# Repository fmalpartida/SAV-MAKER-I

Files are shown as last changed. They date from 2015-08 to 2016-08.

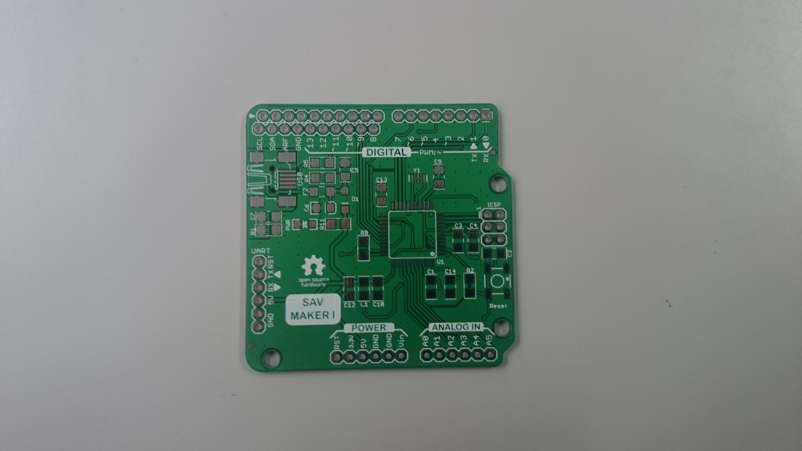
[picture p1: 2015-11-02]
assembly guide/Images/PCBWithoutComponents.JPG

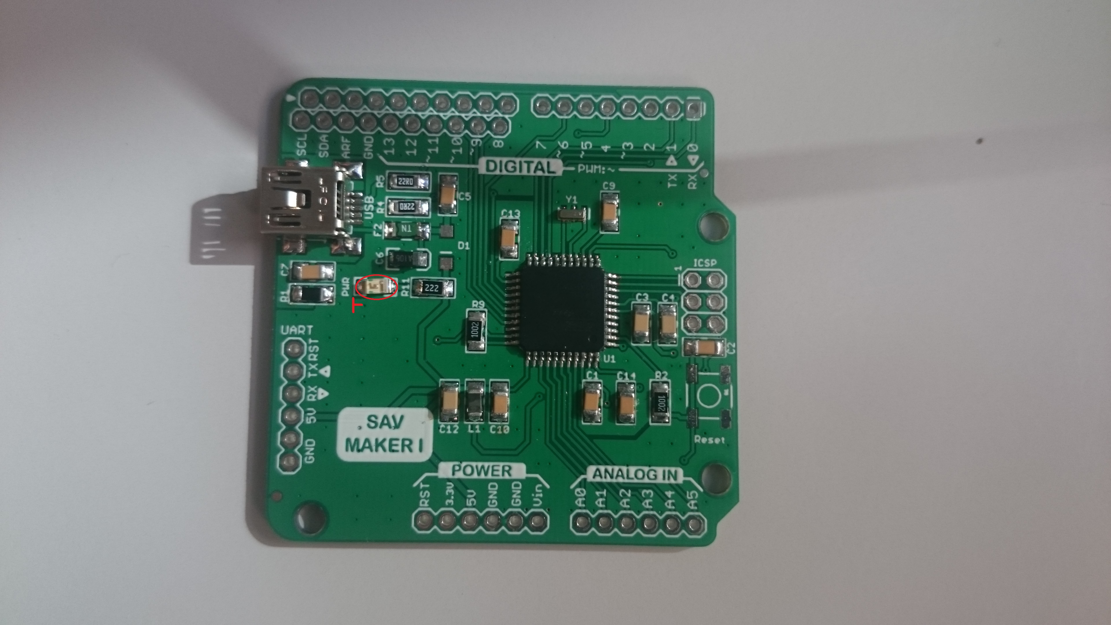
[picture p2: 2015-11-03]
assembly guide/Images/PlacingLed.JPG

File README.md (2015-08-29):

# SAV-MAKER-I
## Introduction

The SAV MAKER I is an “open hardware” project made in Spain and based on the popular [vinciDuino board](https://bitbucket.org/fmalpartida/vinciduino/wiki/Home), 
predecessor of Arduino's Leonardo board and fully compatible with it. 
This development has been carried out for the Telecom Engineering "Applied Electronics" course carried out in the
UMA (Universidad de Málaga). On day one, students will receive a bare PCB and a set of components to assemble and 
use it on some of their course projects.

![SAV MAKER I Rev A] (https://github.com/fmalpartida/SAV-MAKER-I/blob/master/images/SAV%20MAKER%20I%20Rev%20A%20-%20PCBs.JPG)

The SAV MAKER I is an “open hardware” project, a board with an 8-bit microcontroller similar to the Arduino Leonardo
and fully compatible with it. The spirit behind it is for students to be able to build and user their own tools, 
analyse, build on and share their work.
At the end of the year, the board will be revised with their contributions, and who knows, we may use the highest rated board
on next year's course. It will be fun to see how the board evolves over the years.

Beign an open project where anyone can be part of the design team; anyone can bring knowledge, comments and ideas for 
developing other Arduino compatible training board or a programmable board using the Atmel environment without an 
external programmer. It is not limited to students. However, in comparison with other similar “open hardware” projects the 
SAV MAKER I has been designed for people to learn, build and use it while being cost effective. The cost has been optimized
as much as possible to accomodate any budget and pursue the real open hardware’s spirit.

## Wiki contents
* [SAV MAKER I wiki home](https://github.com/fmalpartida/SAV-MAKER-I/wiki)
* [Specifications](https://github.com/fmalpartida/SAV-MAKER-I/wiki/Specifications)
* [Board assembly and mechanical drawings](https://github.com/fmalpartida/SAV-MAKER-I/wiki/Mechanical-drawings-and-component-placement)
* [Board assembly step by step](https://github.com/fmalpartida/SAV-MAKER-I/wiki/Assembly-guide)

## Licensing
All information contained herein is licensed under [CERN OHL](http://www.ohwr.org/attachments/2388/cern_ohl_v_1_2.txt) (please refer to license file for details), so if someone 
wants to use this information to assemble kits, sell boards, etc. … feel free to do it.

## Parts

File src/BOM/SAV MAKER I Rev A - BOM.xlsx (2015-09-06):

Qty | Value | Parts | Device | Mouser part | Price | TOTAL
3 |  | JP3, JP5, JP6 | M06SIP |  |  | 0
1 |  | JP4 | M081X08 |  |  | 0
1 |  | S1 | TAC_SWITCHSMD | PTS525S | 0.23 | 0.23
7 | 0.1uF | C1, C2, C5, C9, C10, C13, C14 | CAP1206 | VJ1206Y104KXXCW1BC | 0.028 | 0.196
2 | 10K | R2, R9 | R-US_R1206 | CRCW120610K0FKEA | 0.029 | 0.058
1 | 10uF | C6 | CAP_POL1206 | F931A106MAA | 0.1 | 0.1
1 | 1206L | F2 | PTC1206_L | 504-PTS120616V025 | 0.29 | 0.29
1 | 1M | R1 | R-US_R1206 | RC1206FR-071ML | 0.009 | 0.009
3 | 1uF | C3, C4, C12 | CAP1206 | VJ1206Y105MXJTW1BC | 0.033 | 0.099
2 | 22R | R4, R5 | R-US_R1206 | ERJ-8ENF22R0V | 0.019 | 0.038
1 | 2K2 | R11 | R-US_R1206 | CRCW12062K20JNEA | 0.012 | 0.012
1 | 4.7nF | C7 | CAP1206 | VJ1206Y472KXXCW1BC | 0.03 | 0.03
1 | ATMEGA32U4-AU | U1 | ATMEGA32U4-AU | ATMEGA32U4-AU | 4.91 | 4.91
1 | AVR_SPI_PRG_6PTH | J2 | AVR_SPI_PRG_6PTH |  |  | 0
1 | MINI USB | USB | MINI-USB-SCHIELD-32005-201 | 10033526-N3212LF | 0.54 | 0.54
1 | Ferrite | L1 | WE-CBF_1206W | 2512061027Y1 | 0.057 | 0.057
2 | M10";M10"" | Header 10 | 1X10 |  |  | 0
1 | MBR0520LT | D1 | MBR0520LT | MBR0520LT1G | 0.2 | 0.2
1 | RESONATORSMD | Y1 | RESONATORSMD | CSTCE16M0V53-R0 | 0.274 | 0.274
1 | Red | PWR | LED1206 | SML-LXF1206GC-TR | 0.09 | 0.09
1 | SAV Maker I | A | BOARD_INFO_BMP_20 |  | 4.5 | 4.5
 |  |  |  |  | TOTAL | 11.633

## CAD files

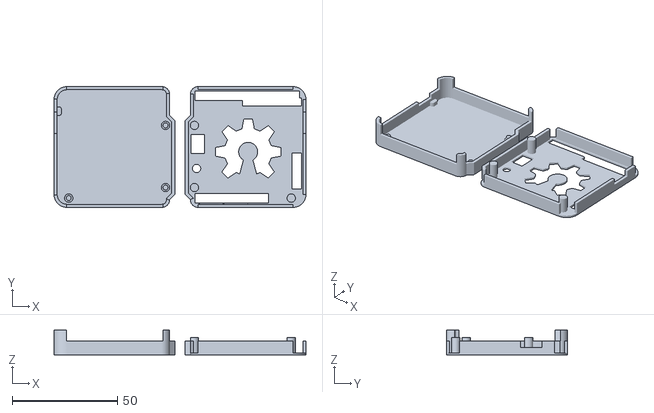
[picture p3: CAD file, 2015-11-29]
3D models/STL Files/SAV_M_I_CASE_v1.4.stl
119.6 x 57.4 x 11.8

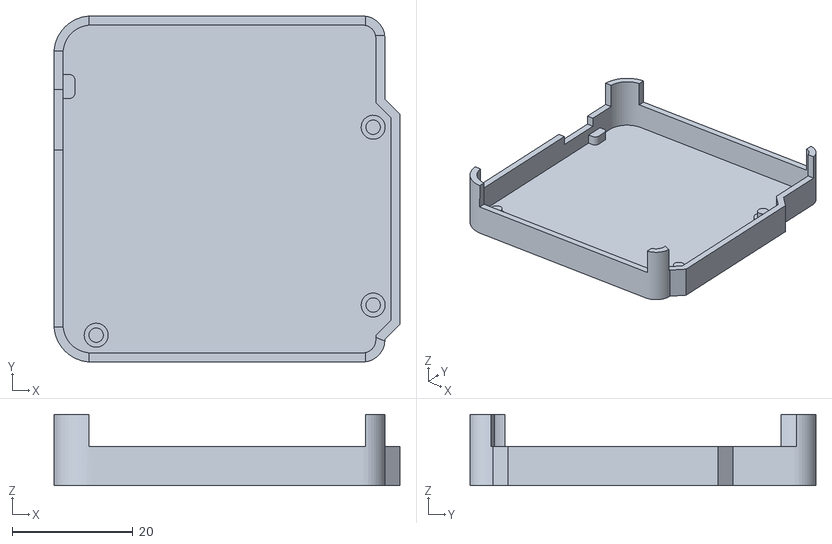
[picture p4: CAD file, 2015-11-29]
3D models/STL Files/SAV_M_I_CASE_v1.3_bottom.stl
57.4 x 57.4 x 11.8

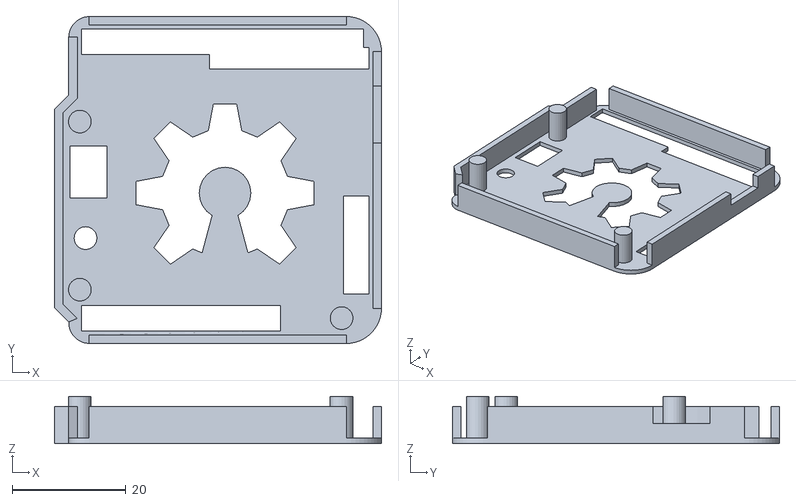
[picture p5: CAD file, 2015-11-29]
3D models/STL Files/SAV_M_I_CASE_v1.4_top.stl
57.4 x 57.4 x 8.30

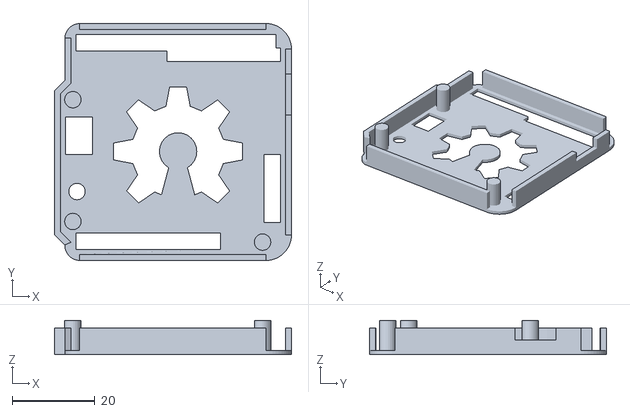
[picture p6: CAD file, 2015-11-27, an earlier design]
3D models/STL Files/SAV_M_I_CASE_v1.3_top.stl
57.4 x 57.4 x 8.30

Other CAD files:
3D models/STL Files/SAV_M_I_CASE_v1.3.stl
3D models/STL Files/SAV_M_I_CASE_v1.2_bottom.stl
3D models/Sketchup Files/SAV_M_I_CASE_v1.2.skp
3D models/Sketchup Files/SAV_M_I_CASE_v1.3.skp
3D models/Sketchup Files/SAV_M_I_CASE_v1.4.skp

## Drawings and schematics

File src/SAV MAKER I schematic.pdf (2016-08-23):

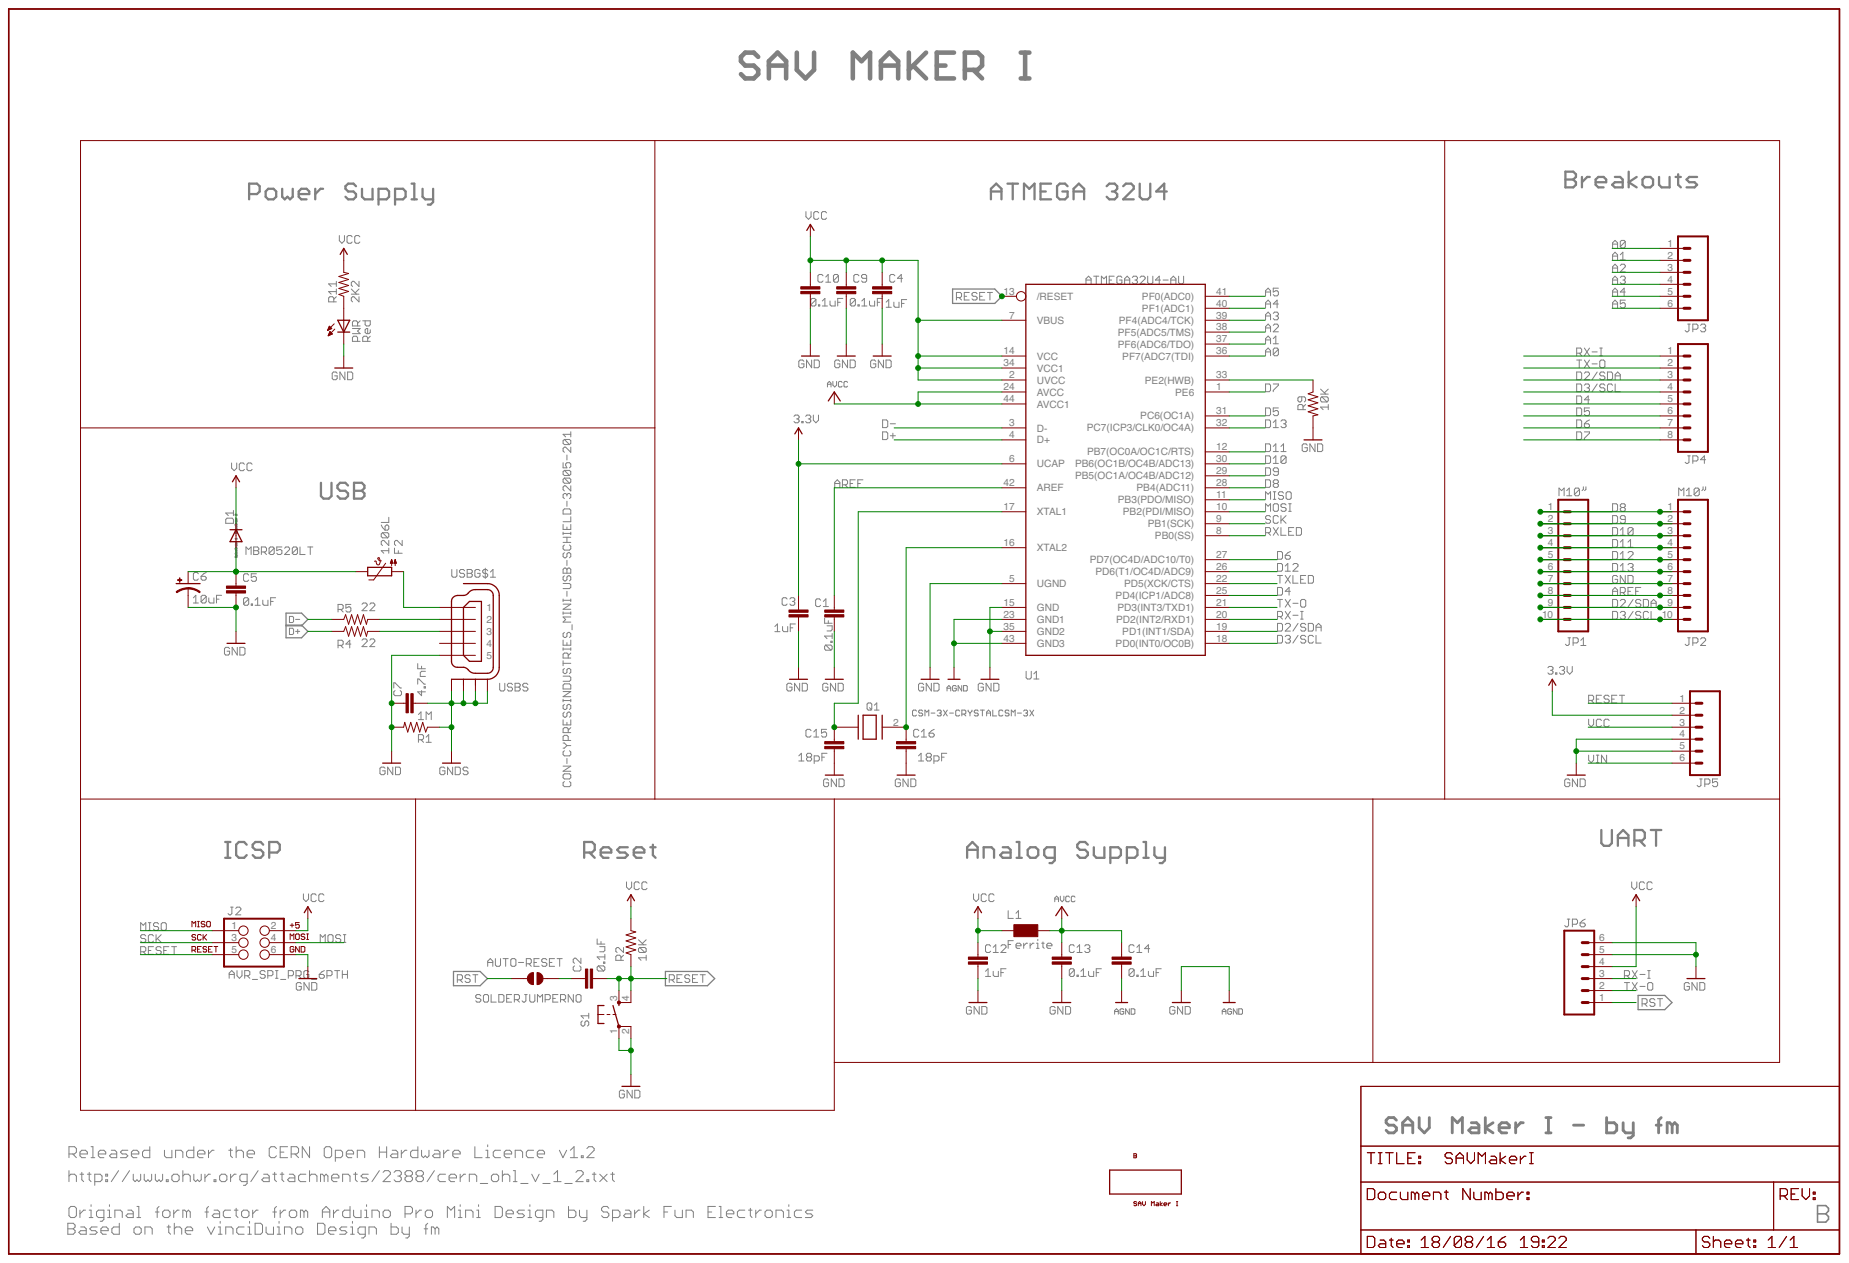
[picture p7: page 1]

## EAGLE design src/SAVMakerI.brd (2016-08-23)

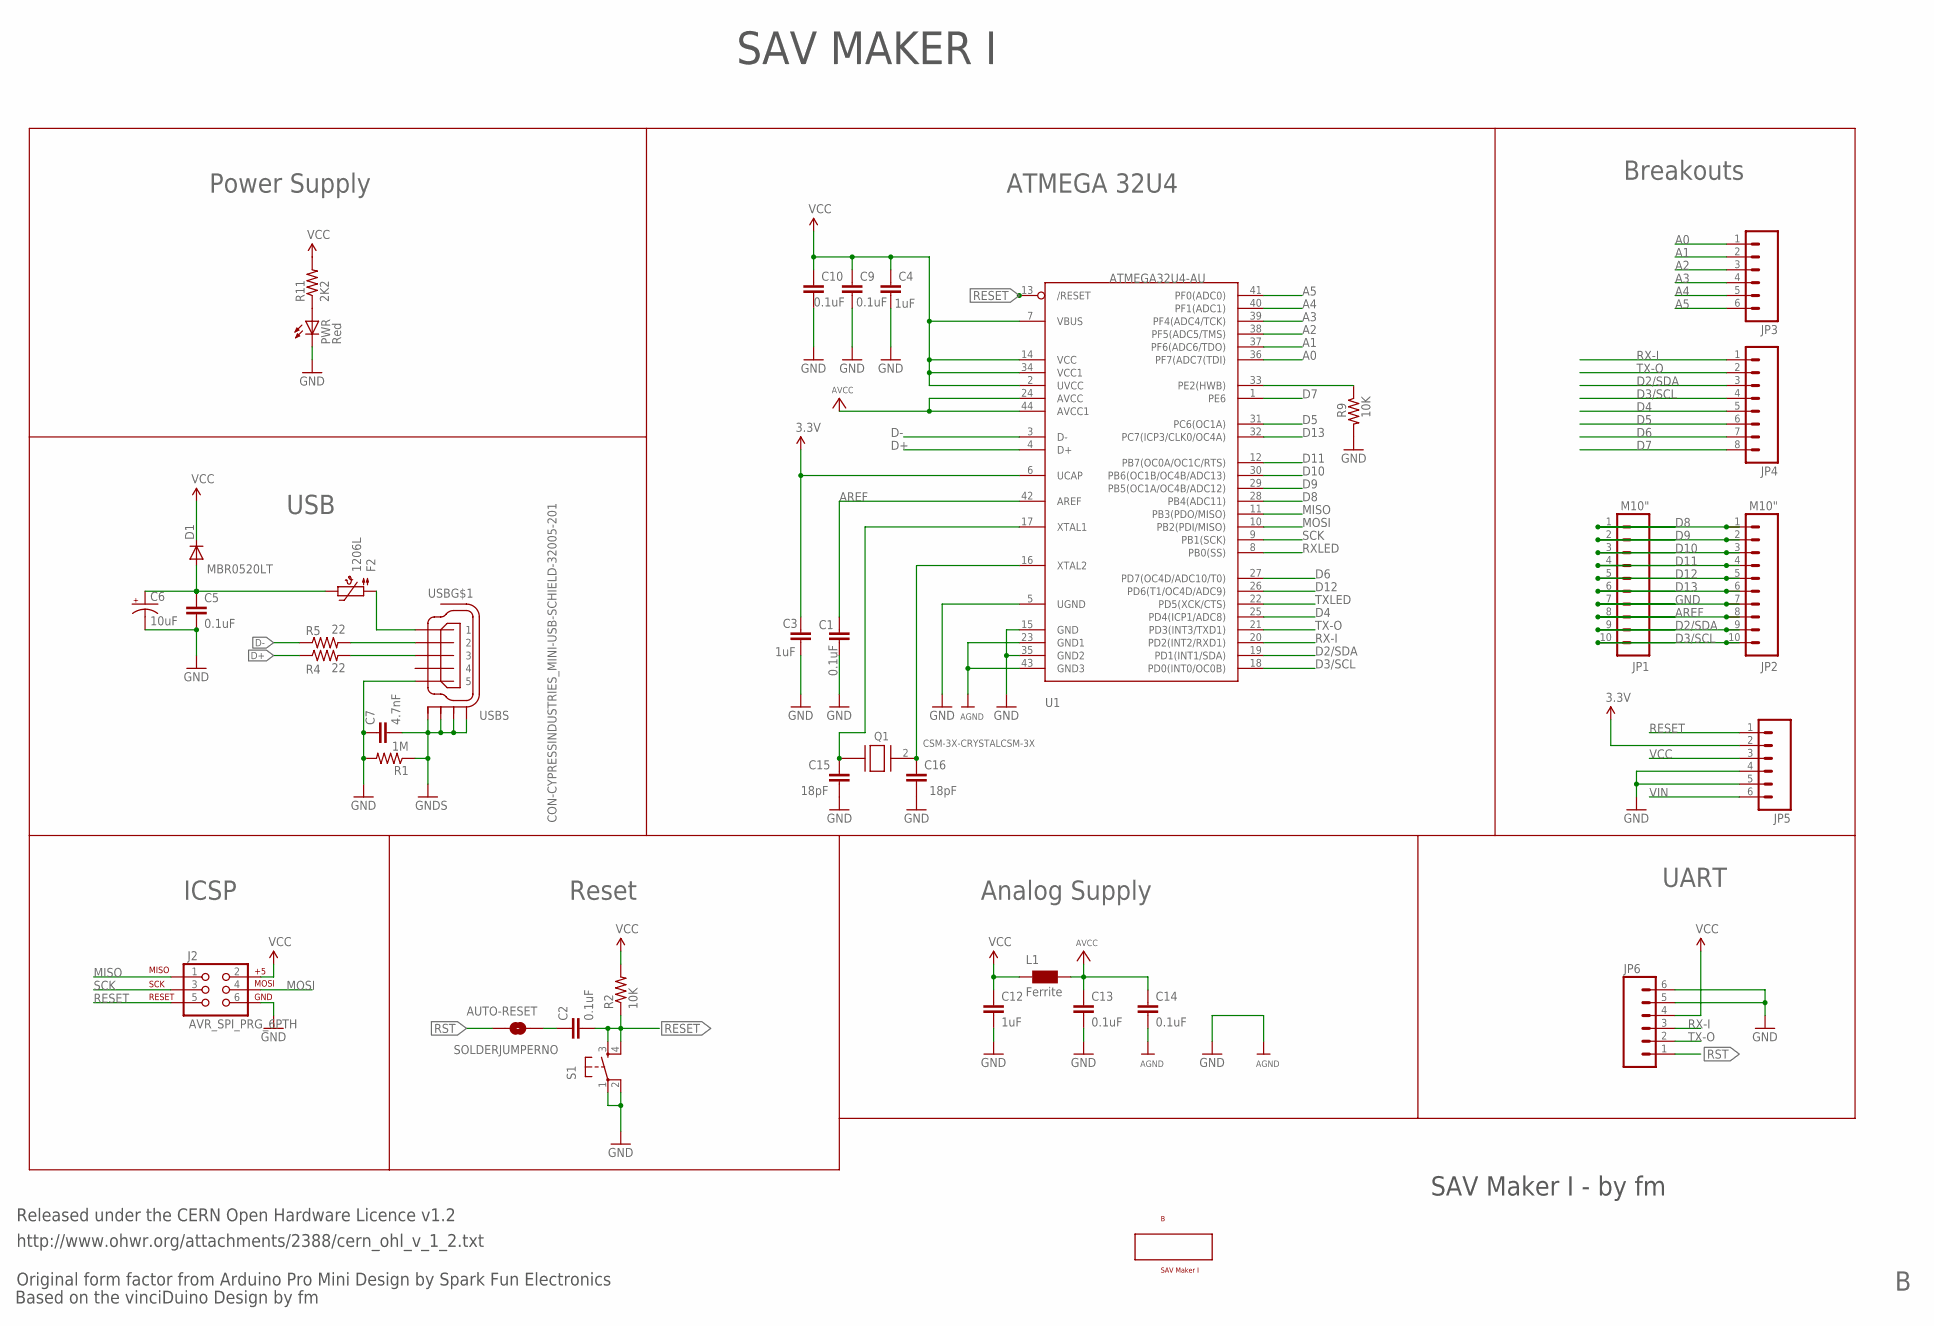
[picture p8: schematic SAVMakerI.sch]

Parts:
AUTO-RESET: SOLDERJUMPERNO; SJ_2S-NO
B: SAV Maker I; BOARD_INFO_BMP
C1, C2, C5, C9, C10, C13, C14: 0.1uF; 1206
C3, C4, C12: 1uF; 1206
C6: 10uF; EIA3216
C7: 4.7nF; 1206
C15, C16: 18pF; 1206
D1: MBR0520LT; SOD123
F2: 1206L; 1206_PTC
J2: AVR_SPI_PRG_6PTH; 2X3
JP1, JP2: M10"; 1X10
JP3, JP5, JP6: M06SIP; 1X06
JP4: M081X08; 1X08
L1: Ferrite; 1206W
PWR: Red; LED-1206
Q1: CSM-3X-CRYSTALCSM-3X; CSM-3X
R1: 1M; R1206
R2, R9: 10K; R1206
R4, R5: 22; R1206
R11: 2K2; R1206
S1: TAC_SWITCHSMD; TACTILE_SWITCH_SMD
U1: ATMEGA32U4-AU; ADAFRUIT_TQFP44
USB: CON-CYPRESSINDUSTRIES_MINI-USB-SCHIELD-32005-201; CON-CYPRESSINDUSTRIES_32005-201

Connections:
3.3V: C3.1, JP5.2, U1.6 (UCAP)
A0: JP3.1, U1.36 (PF7(ADC7(TDI))
A1: JP3.2, U1.37 (PF6(ADC6/TDO))
A2: JP3.3, U1.38 (PF5(ADC5/TMS))
A3: JP3.4, U1.39 (PF4(ADC4/TCK))
A4: JP3.5, U1.40 (PF1(ADC1))
A5: JP3.6, U1.41 (PF0(ADC0))
AREF: C1.2, JP1.8, JP2.8, U1.42 (AREF)
AVCC: C13.1, C14.1, L1.2, U1.24 (AVCC), U1.44 (AVCC1)
D2/SDA: JP1.9, JP2.9, JP4.3, U1.19 (PD1(INT1/SDA))
D3/SCL: JP1.10, JP2.10, JP4.4, U1.18 (PD0(INT0/OC0B))
D4: JP4.5, U1.25 (PD4(ICP1/ADC8))
D5: JP4.6, U1.31 (PC6(OC1A))
D6: JP4.7, U1.27 (PD7(OC4D/ADC10/T0))
D7: JP4.8, U1.1 (PE6)
D8: JP1.1, JP2.1, U1.28 (PB4(ADC11))
D9: JP1.2, JP2.2, U1.29 (PB5(OC1A/OC4B/ADC12))
D10: JP1.3, JP2.3, U1.30 (PB6(OC1B/OC4B/ADC13))
D11: JP1.4, JP2.4, U1.12 (PB7(OC0A/OC1C/RTS))
D12: JP1.5, JP2.5, U1.26 (PD6(T1/OC4D/ADC9))
D13: JP1.6, JP2.6, U1.32 (PC7(ICP3/CLK0/OC4A))
D+: R4.1, U1.4 (D+)
D-: R5.1, U1.3 (D-)
GND: C1.1, C3.2, C4.2, C5.2, C6.C (-), C7.1, C9.2, C10.2, C12.2, C13.2, C14.2, C15.2, C16.2, J2.6, JP1.7, JP2.7, JP5.4, JP5.5, JP6.5, JP6.6, PWR.C, R1.2, R9.2, S1.1, S1.2, U1.5 (UGND), U1.15 (GND), U1.23 (GND1), U1.35 (GND2), U1.43 (GND3), USB.5
GNDS: C7.2, R1.1, USB.M1 (S1), USB.M2 (S2), USB.M3 (S3), USB.M4 (S4)
MISO: J2.1, U1.11 (PB3(PDO/MISO))
MOSI: J2.4, U1.10 (PB2(PDI/MISO))
unnamed: R5.2, USB.2
unnamed: C16.1, Q1.2, U1.16 (XTAL2)
unnamed: C15.1, Q1.1, U1.17 (XTAL1)
unnamed: R4.2, USB.3
unnamed: R9.1, U1.33 (PE2(HWB))
unnamed: AUTO-RESET.2, C2.1
unnamed: F2.1, USB.1
unnamed: PWR.A, R11.1
RESET: C2.2, J2.5, JP5.1, R2.1, S1.3, S1.4, U1.13 (/RESET)
RST: AUTO-RESET.1, JP6.1
RX-I: JP4.1, JP6.3, U1.20 (PD2(INT2/RXD1))
RXLED: U1.8 (PB0(SS))
SCK: J2.3, U1.9 (PB1(SCK))
TX-O: JP4.2, JP6.2, U1.21 (PD3(INT3/TXD1))
TXLED: U1.22 (PD5(XCK/CTS))
VBUS: C5.1, C6.A (+), D1.A, F2.2
VCC: C4.1, C9.1, C10.1, C12.1, D1.C, J2.2, JP5.3, JP6.4, L1.1, R2.2, R11.2, U1.2 (UVCC), U1.7 (VBUS), U1.14 (VCC), U1.34 (VCC1)
VIN: JP5.6

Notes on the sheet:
Released under the CERN Open Hardware Licence v1.2
http://www.ohwr.org/attachments/2388/cern_ohl_v_1_2.txt
Original form factor from Arduino Pro Mini Design by Spark Fun Electronics
Based on the vinciDuino Design by fm
Power Supply
USB
Reset
ICSP
Analog Supply
UART
Breakouts
ATMEGA 32U4
SAV MAKER I
SAV Maker I - by fm

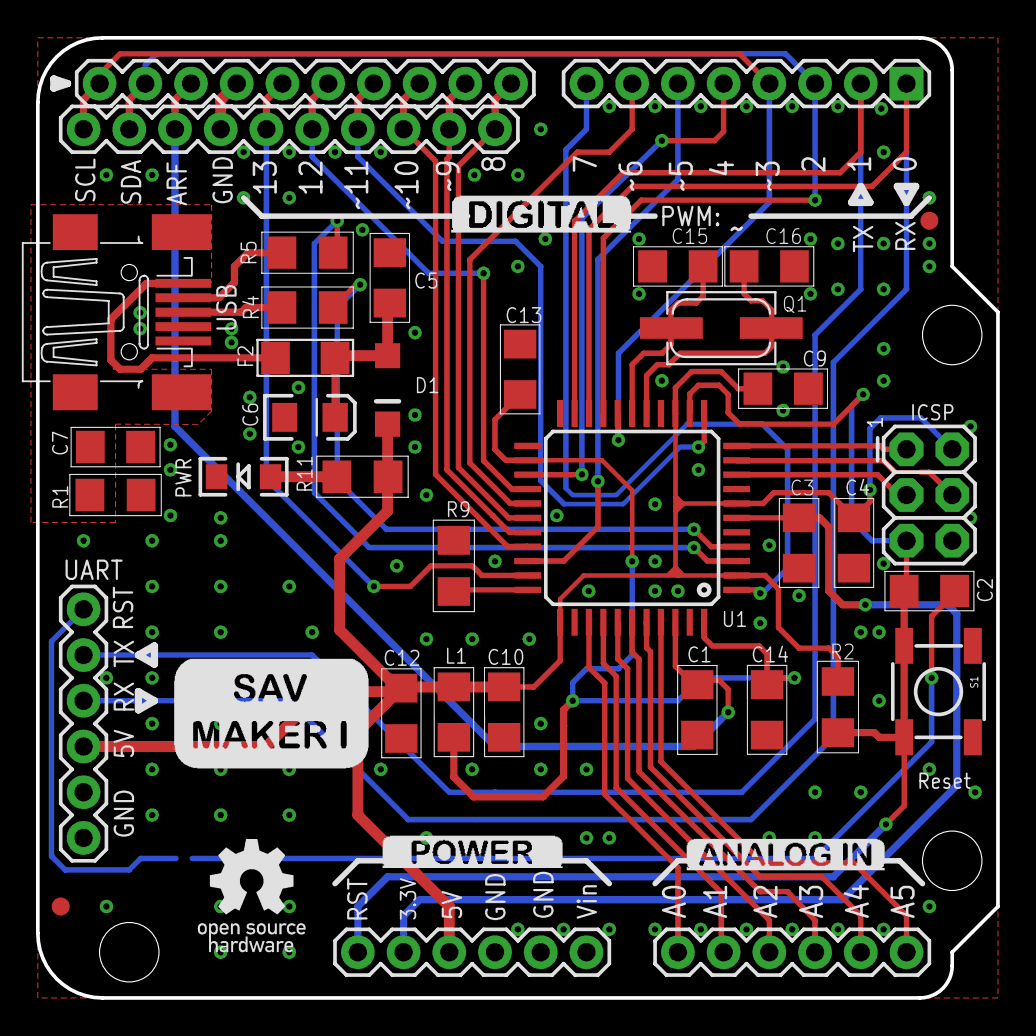
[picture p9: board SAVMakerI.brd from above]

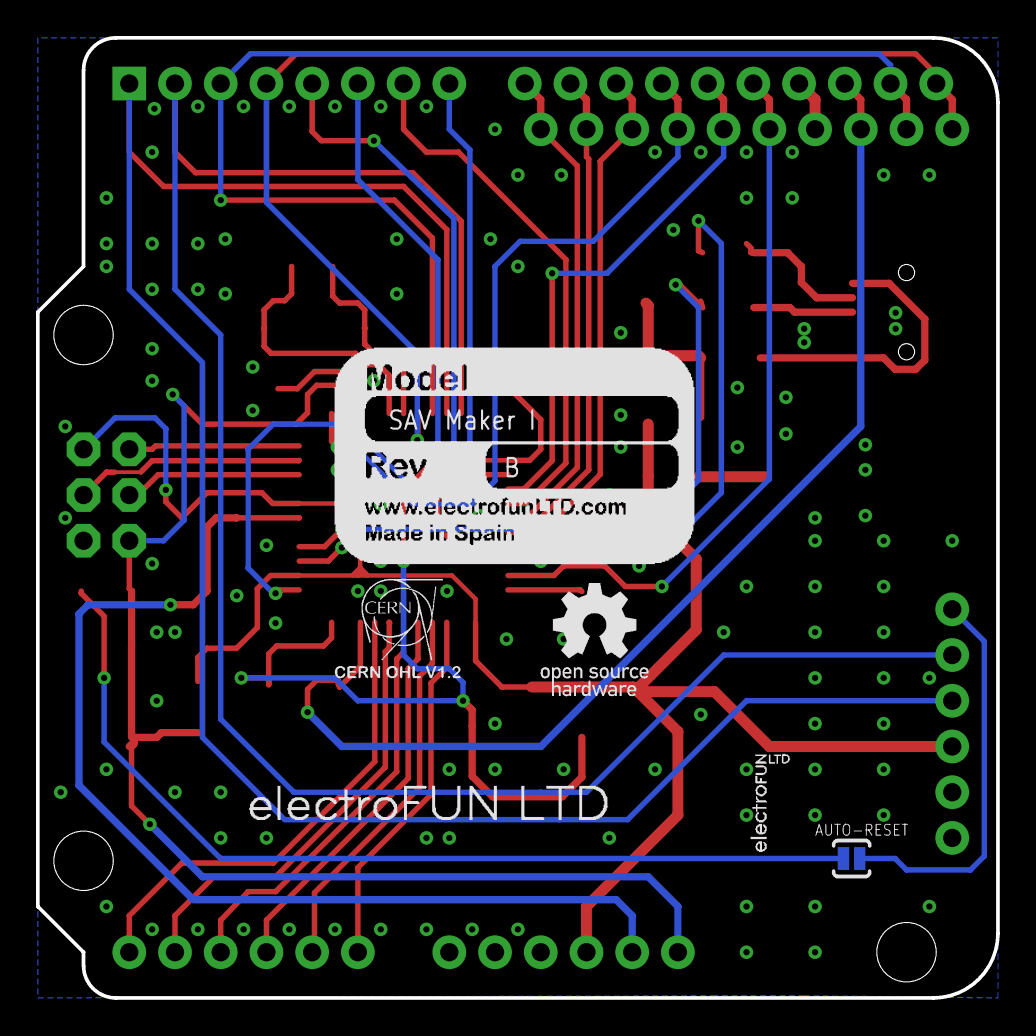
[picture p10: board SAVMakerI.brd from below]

Board: 2 copper layers, 53.3 x 53.3 mm, 50 parts (5 on the bottom side), 42 nets.

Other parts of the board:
U$1, U$3, U$5: STAND-OFF
U$2, U$4: FIDUCIAL1X2; FIDUCIAL-1X2
U$9: ELECTROFUN_STRIP
U$10: SAVMAKERI
U$13, U$15: OSHW
U$14: CERN_OHL
U$16: ANALOG_BMP
U$17: DIGITAL_BMP
U$18: POWER_BMP

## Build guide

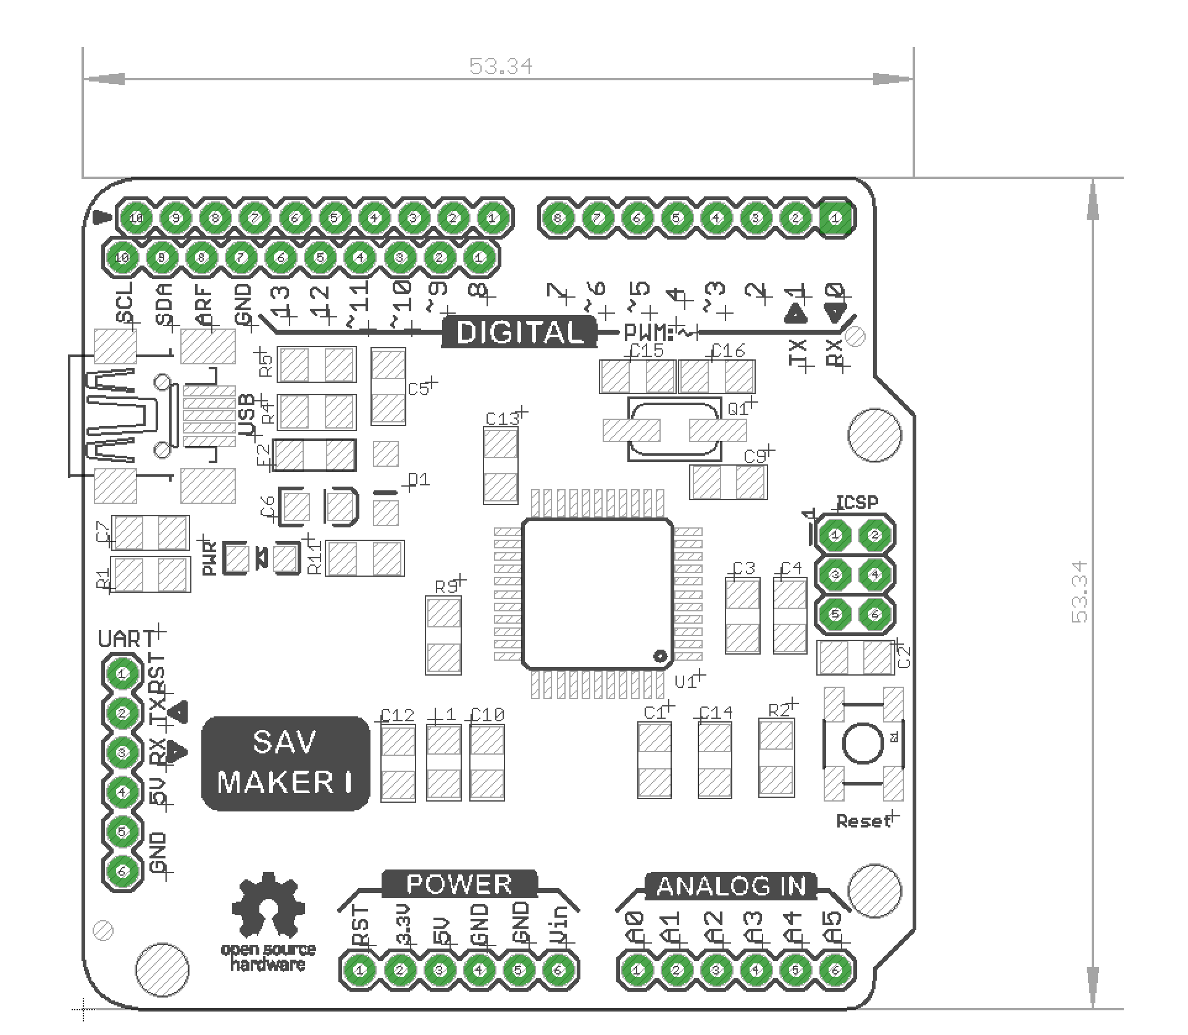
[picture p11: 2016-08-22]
images/RevB/SAV MAKER I RevB - assembly.png

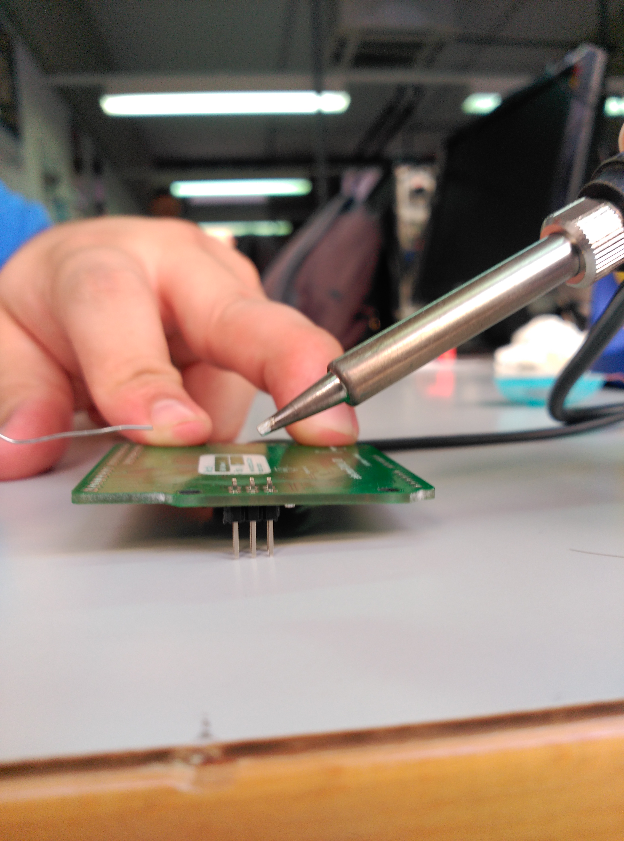
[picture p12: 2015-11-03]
images/Photos/10) Montaje pines.jpg

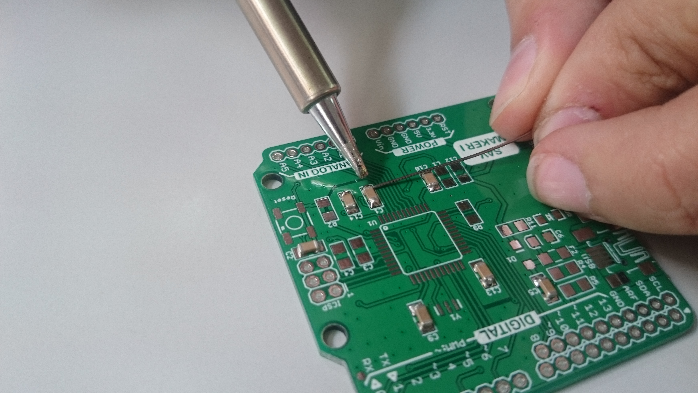
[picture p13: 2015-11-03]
assembly guide/Images/PlacingCapacitors2.JPG

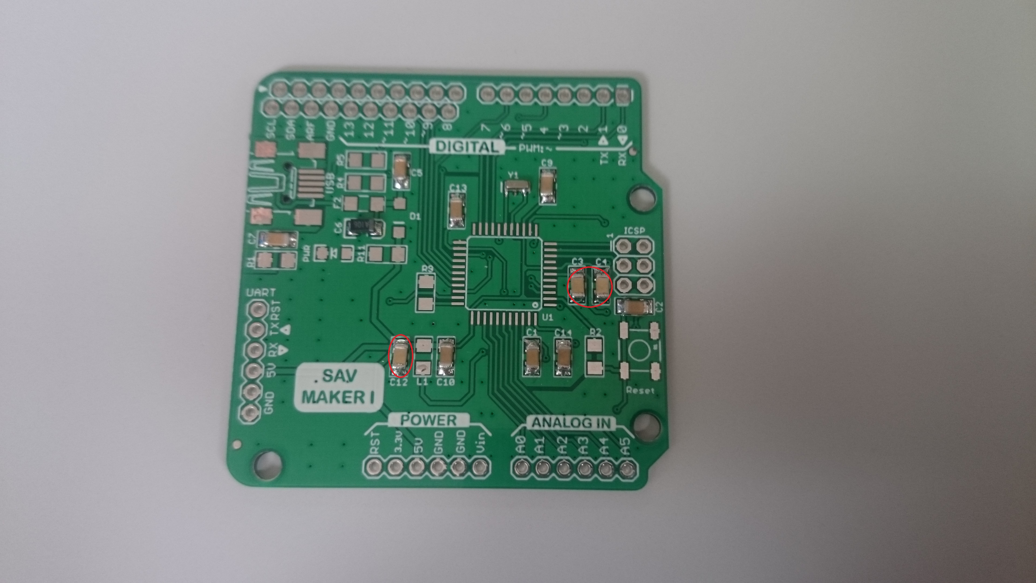
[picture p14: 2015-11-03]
assembly guide/Images/Capacitors1uF.JPG

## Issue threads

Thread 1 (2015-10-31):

Assembly-Picture1

the-mentalaist, 2015-10-31:
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

areyesl, 2015-11-02:
Hola,
Imagino que abriste este issue porque querías incrustar esta imagen en la wiki. Si era eso, ten en cuenta que para incrustar imagenes es necesario que éstas estén en un repositorio Github.
Saludos,
Arcadio

fmalpartida, 2015-11-02:
Exacto. Deje un directorio imagen para ir subiendo todas las imágenes y enlazarlas en la wiki.

the-mentalaist, 2015-11-02:
Pues sí, era por eso. El problema es que no sé cómo subir las imágenes al repositorio.

fmalpartida, 2015-11-09:
Looking nice the assembly manual.

Closed 2015-11-09.

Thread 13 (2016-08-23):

Schematic PDF is mirrored

areyesl, 2016-08-23:
New schematic for Rev B in SAV-MAKER-I/src/SAV MAKER I schematic.pdf is mirrored

fmalpartida, 2016-08-23:
I have already changed the wiki for the board layout and 3D renders.

fmalpartida, 2016-08-23:
Updated PDF schematic file with revision B.

Closed 2016-08-23.

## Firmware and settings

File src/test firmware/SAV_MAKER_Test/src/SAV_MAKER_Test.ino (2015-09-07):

const int numPins = 25;

void setup()
{

 for ( int i = 0; i < numPins; i++ )
 {
    pinMode ( i, OUTPUT );
 }
 
}

void loop()
{
  static int pinOut = 0;
  
  for ( int i = 0; i < numPins; i++ )
  {
     digitalWrite ( i, pinOut );
  }
  pinOut ^= 1; // toggle the output for next round
  delay ( 1 );
}
  

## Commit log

2015-08-20 First public version of the board.
    [SAV MAKER I Rev A - BOM.xlsx, SAVMakerI.brd, SAVMakerI.sch]
2015-08-20 Added PDF schematic and board 3D renders.
2015-08-20 Added mechanical and assembly guide.
    [SAV MAKER I Rev A - BOM.xlsx]
2015-08-20 Update README.md
    Added board assembly information.
2015-09-06 Added board characteristics.
    [SAV MAKER I Rev A - BOM.xlsx]
2015-09-07 Added test firmware to check board's assembly.
2015-11-02 first image for the assembly guide
    This is an example of image uploaded to the repository for embeding them
    in the assembly guide wiki
2015-11-03 /Users/MYN/Documents/UMA/Creativa/SAVMAKERI/imagen2.JPG
    Estoy probando a ver si puedo subir la imagen
2015-11-03 Creo que estoy cerca
    /Users/MYN/Documents/UMA/Creativa/SAVMAKERI/imagen2.JPG
2015-11-03 Espero que sí
    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
2015-11-03 Prueba
    Es una prueba para subir una imagen.
2015-11-03 Prueba de adición de fotos
    A ver si ahora sí...
2015-11-03 Nuevas imágenes
    Imágenes para la guía
2015-11-03 Added photos to assembly guide.
2015-11-09 Added assembly guide PDF
2015-11-09 Old assembly guide removed. Added new assembly guide.
2015-11-10 New folder with all things about assembly guide. Removed duplicated photos.
2015-11-26 primer fichero de prueba
2015-11-27 Adding 3D models
    SAV MAKER I 3d model housing
    [SAV_M_I_CASE_v1.2.skp, SAV_M_I_CASE_v1.2_bottom.stl, SAV_M_I_CASE_v1.3.skp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]
2015-11-29 Update 1
    Changes in the pin holes and some adjustments to fit them well the top
    and bottom parts.
    [SAV_M_I_CASE_v1.3_bottom.stl, SAV_M_I_CASE_v1.4.skp, SAV_M_I_CASE_v1.4.stl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]
2016-08-18 Added oscillator replacing the resonator.
    [SAVMakerI.brd, SAVMakerI.sch]
2016-08-18 Uploaded gerber files.
2016-08-18 Minor modifications to routes.
    [SAVMakerI.brd, SAVMakerI.sch]
2016-08-18 Updated routing.
    [SAVMakerI.brd]
2016-08-18 Updated documentation: schematic and 3D renders.
    [SAVMakerI.brd]
2016-08-22 Updated placement and schematic.
    [SAVMakerI.GBL, SAVMakerI.GBO, SAVMakerI.GBS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]
2016-08-23 Empty assembly gude removed from src folder
    this was a student try
2016-08-23 Updated mirrored file.
    [SAVMakerI.brd]
2016-10-26 Added images PCB RevB top and bottom assembled.
